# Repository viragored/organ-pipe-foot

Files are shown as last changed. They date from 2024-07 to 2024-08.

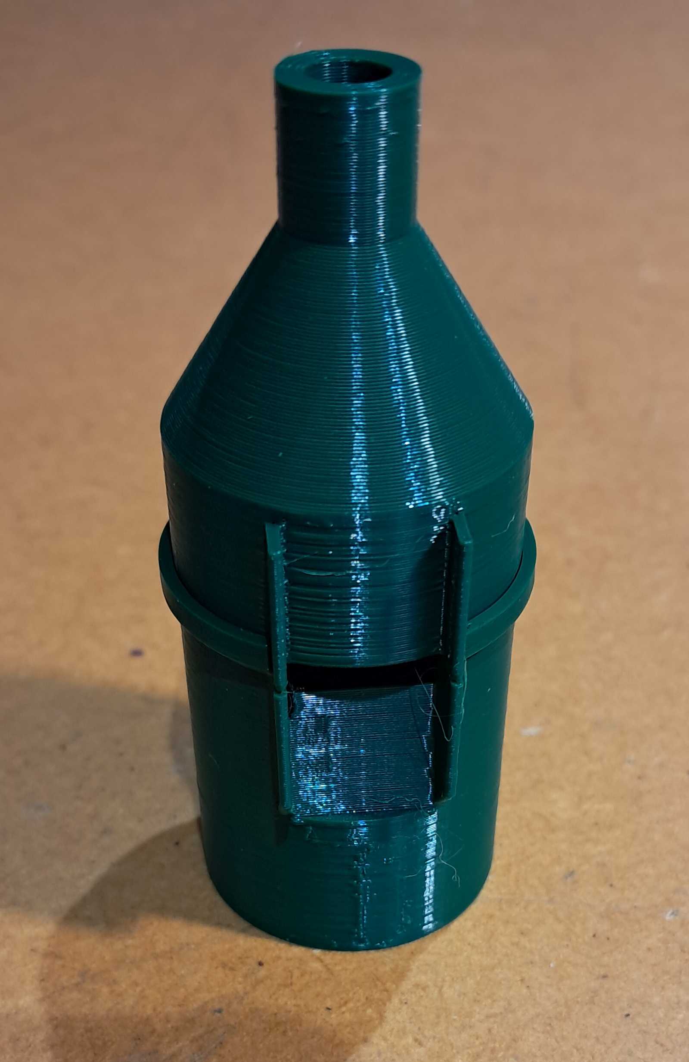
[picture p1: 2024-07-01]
foot 3.jpg

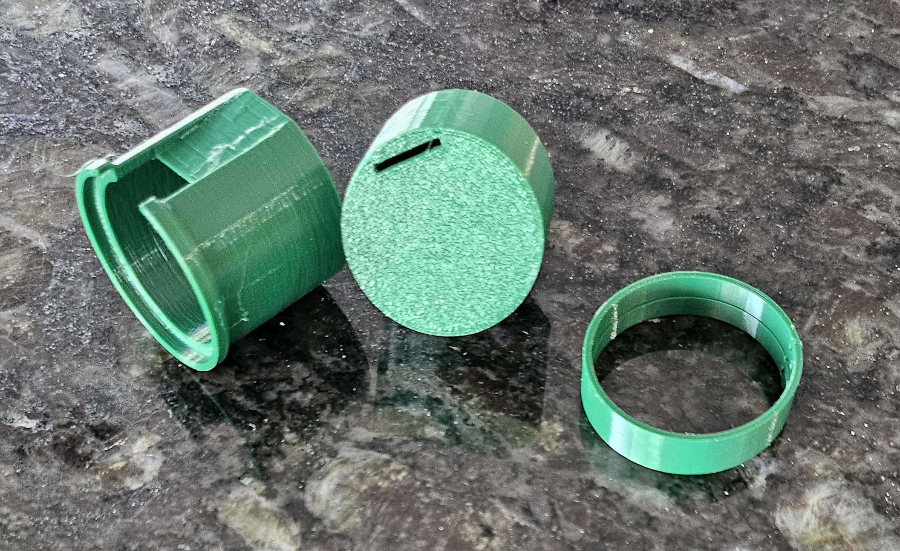
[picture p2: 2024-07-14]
V2 pic 1.jpg

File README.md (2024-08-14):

# organ-pipe-foot
OpenSCAD code to create organ pipe feet, customisable for size and shape

Aim: Produce a foot that must print without supports, based on these premises:
*  Walls will be thick enough to support PVC pipe while organ being moved, eg on a cart over rough ground
*  PVC pipe will be used for the resonating pipe
*  The pipe will be stopped, not open
*  Frequency will be given
*  Mouth height calculated using frequency in this formula (stopped pipe)
        MH = [3.018 - 0.233 ln f]^5 (MH = Mouth Height; f = Frequency; ln = natural log)
*  Flue (the slot in the languid through which air is blown) needs printing at high resolution for accuracy
*  flue_width is calculated from the Ising formula (link below)
*  Stem diameter, inside diameter of the stem connecting to the windchest
*  Foot length - from windchest to mouth to resonator = user's choice
*  Upper lip offset - achieved by aligning flue on languid
        [(https://www.colinpykett.org.uk/physics-of-voicing-organ-flue-pipes.htm#Offset)]

References:
*  [Formula using windsheet width (the thickness of the air stream coming from the flue) to get Ising's number at https://www.mmdigest.com/Tech/isingform.html
    and https://www.rwgiangiulio.com/math/wst.htm [Beware, Imperial units]
    windsheet_thickness =	(I^2 * f^2 * ρ * H^3) / 2P
        I = Ising's number; p = air density; P = air pressure; H = mouth height ]
*  Mouth height: a = 440Hz, stopped MH = 8.1 (https://www.rwgiangiulio.com/math/mouthheight.htm)
*  [Pipe length is: flue to stopper base - the pipe width + stopper 
        pipe_length = 3386 / f - pipe_internal_diameter (plus a bit of headroom?)
        (https://www.rwgiangiulio.com/math/pipelength.htm)
        (https://www.ccoors.de/webpipecalc/)]
*  Upper lip offset: (https://www.colinpykett.org.uk/physics-of-voicing-organ-flue-pipes.htm#Offset)

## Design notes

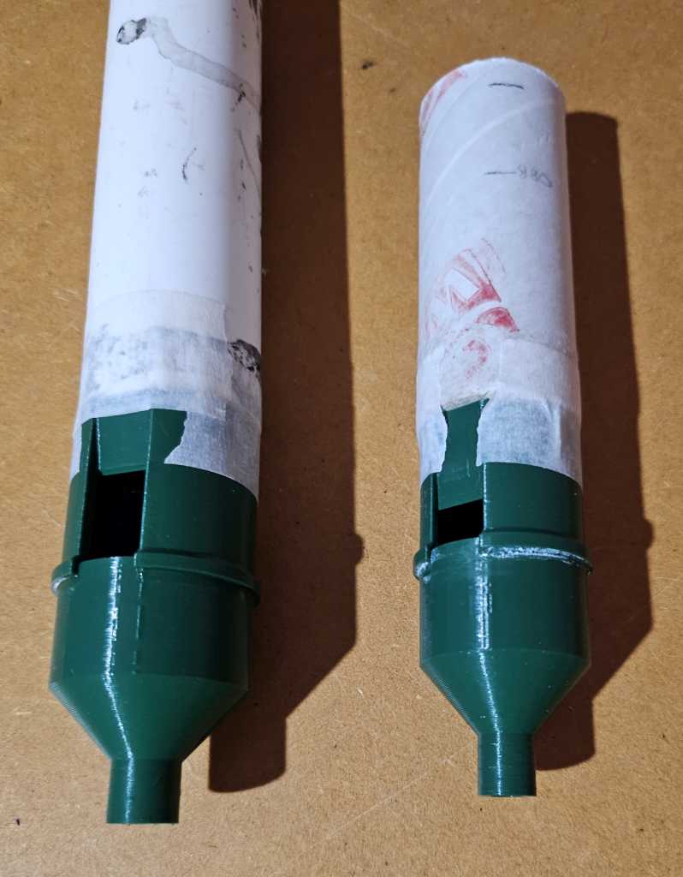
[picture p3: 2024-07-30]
V3 2.jpg

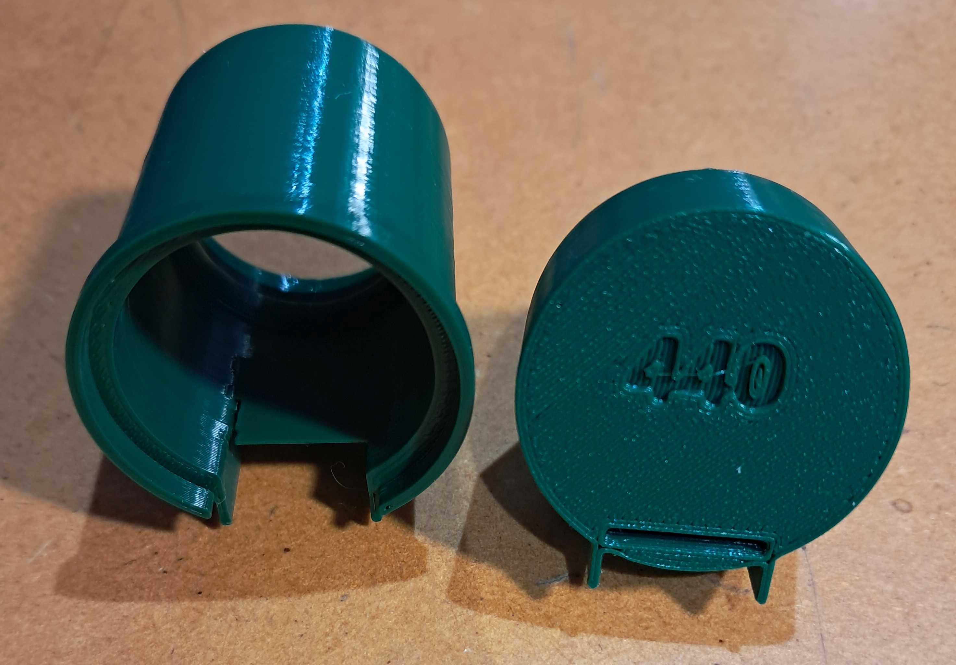
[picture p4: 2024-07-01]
foot 2.jpg

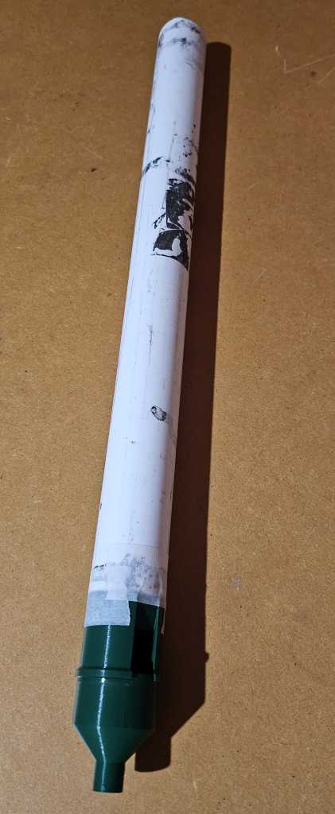
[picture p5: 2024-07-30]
V3 1.jpg

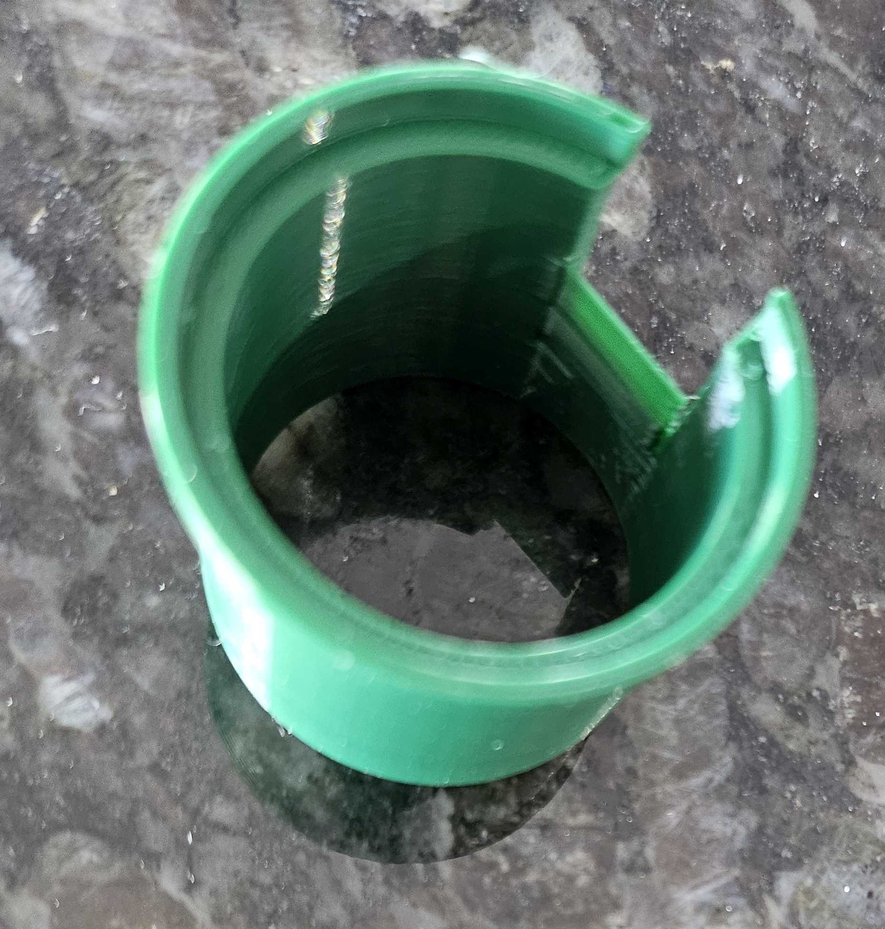
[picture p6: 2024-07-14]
V2 pic 2.jpg

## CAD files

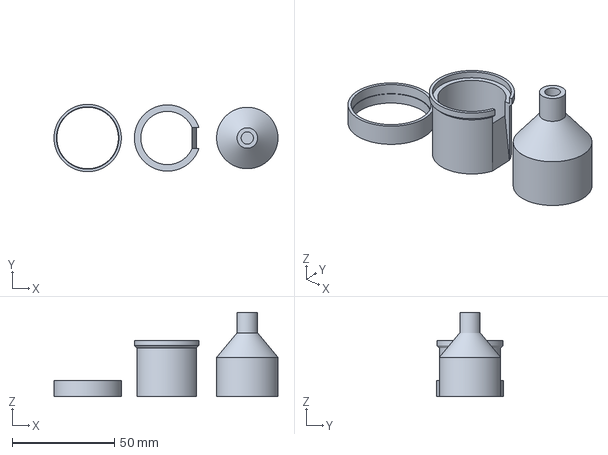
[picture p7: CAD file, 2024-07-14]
2nd prototype 880.3mf
109.4 x 32.9 x 41.3 mm

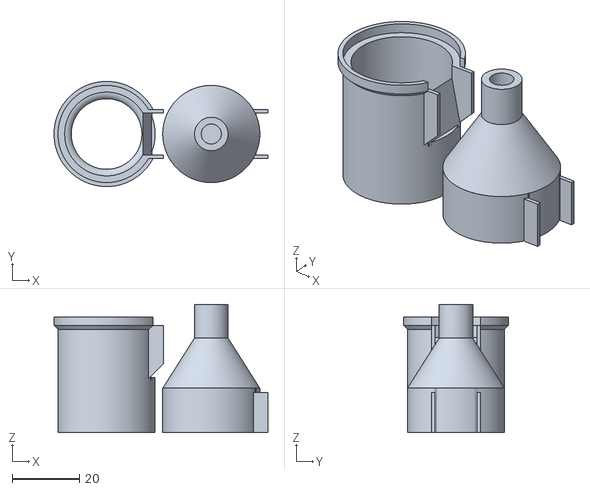
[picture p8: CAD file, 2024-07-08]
1st prototype.stl
63.9 x 31.4 x 38.3

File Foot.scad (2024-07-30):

/*                             Version 3: 23 July 2024
Notes:
Inspiration: 3D model "smaller pipe for 25 mm tube" (https://www.thingiverse.com/thing:6534684/files)
Aim: Produce a foot that must print without supports, based on these premises:
*  Walls will be thick enough to support PVC pipe while organ being moved, eg on a cart over rough ground
*  PVC pipe will be used for the resonating pipe
*  The pipe will be stopped, not open
*  Frequency will be given
*  Ising's number will be given (affects sound character of pipe, used in flue calculation)
*  Pressure of air at the pipe will be given
*  Mouth height calculated using frequency in this formula (stopped pipe)
        MH = [3.018 - 0.233 ln f]^5 (MH = Mouth Height; f = Frequency; ln = natural log)
*  Flue (the slot in the languid through which air is blown) needs printing at high resolution for accuracy
*  Stem diameter, inside diameter of the stem connecting to the windchest
*  Foot length - from windchest to mouth to resonator = user's choice
*  Upper lip offset - achieved by aligning flue on languid
        [(https://www.colinpykett.org.uk/physics-of-voicing-organ-flue-pipes.htm#Offset)]
References:
* Formula using windsheet width (the thickness of the air stream coming from the flue) to get Ising's number at https://www.mmdigest.com/Tech/isingform.html
    and https://www.rwgiangiulio.com/math/wst.htm [Beware, Imperial units : inch_mm = 25.39]
    windsheet_thickness D =	(I^2 * f^2 * )ρ * H^3)) / 2P
        I = Ising's number; p = air density; P = air pressure; H = mouth height 
        Solution from OpenAI: https://chatgpt.com/share/9501fe4e-4f52-485f-864d-c0a950776f9c
*  Pipe length is: flue to stopper base - the pipe width + stopper 
        pipe_length = 3386 / f - pipe_internal_diameter (plus a bit of headroom?) : INCHES !!
        (https://www.rwgiangiulio.com/math/pipelength.htm)  (https://www.ccoors.de/webpipecalc/)
*  Upper lip offset: (https://www.colinpykett.org.uk/physics-of-voicing-organ-flue-pipes.htm#Offset)
TO BE DONE - 
Make top of lip circular up to height of coupler
Harmonic Bridge aka Frein aka Beard? On or Off 
        (https://www.youtube.com/watch?v=bHBOwiEf6FM and Colin Pykett, below)
*/
// Definitions
// Design parameters

// CHOOSE these:
make = "f"; // f makes a foot, s makes a stopper, else makes nothing
ears_on = 1; // 1 = make ears, 0 = no ears
coupler_on = 1; // 1 = make coupler, 0 = no coupler

// SET these:
PVC_outside = 34; // outside diameter of PVC pipe resonator
PVC_inside = 28; // inside diameter of PVC pipe resonator
frequency = 233.08; // A#3 // Hz of target pipe, used to calculate mouth height
//frequency = 174.61; // F3 bass // Hz of target pipe, used to calculate mouth height
pipe_diameter = PVC_inside; // inside diameter of foot - same as PVC inside
stem_diameter = 6; // inside diameter of tube to couple with windchest
stem_length = 10; // length of pipe to couple with windchest
lower_body_length = 12; // length of lower pipe between stem and languid section
lower_top_length = 18; // length of lower section with languid that mates with upper
upper_length = 30; // user choice: length of upper part
// for stopper
disc_thick = 6; // thickness of stopper
knob_height = 25;
knob_diameter = 15;
knob_stand = 8; // height of knob base
knob_stretch = 2; // factor to multiply knob_height
screw_thread = 4; // diameter of fastening screw
screw_head = 8; // diameter of screw head
screw_free = 5; // length of thread to keep unused within knob (remember to add in disc, used to save cutting screws)
nut_diameter = 7.8; // diameter of hex nut across points
nut_thick = 3.2; // thickness of nut
o_ring_thick = 2.2; // thickness of o_ring

// REVIEW these
Ising = 2.5; // Ising's number for type of pipe sound, set mid-range
Pressure = 988; // air pressure reaching pipe, in Pascals : 988 = ~ 4 ins/ 10 cms H2O
rho = 1.2; // standard air density in Kg/M^3
inch_mm = 25.39; // conversion factor
wall_thick = 3; // thickness of walls in this foot
languid_thick = 1.25; // thickness of the languid (flat plate with air hole)
flue_offset_factor = 0.5; // adjust this amount of flue depth relative to lip (negative moves towards centre)
wind_factor = 0.4; // max proportion of pipe diameter that flue can be
ear_thick = 1; // thickness of the ears
ear_height = 5; // ear protrusion
upper_ear_length = 0.75; // proportion of upper body the ears will cover - too long can clash with coupler
collar_thick = 1.2; // thickness of the joining collar
collar_height = 2.5; // height of joining collar
coupler_height = 15; // height of PVC coupler
coupler_thick = 2.5; // thickness of PVC coupler
printer_fit = 0.2; // amount to allow for printer fitting curved parts
// internal parameters quick for preview, smooth curves for render
$fs = $preview ? 1 : 0.15;
$fa = $preview ? 3 : 2;
epsilon = 0.01; // tiny offset to ensure cuts go through
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

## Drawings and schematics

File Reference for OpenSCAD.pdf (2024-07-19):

0

1

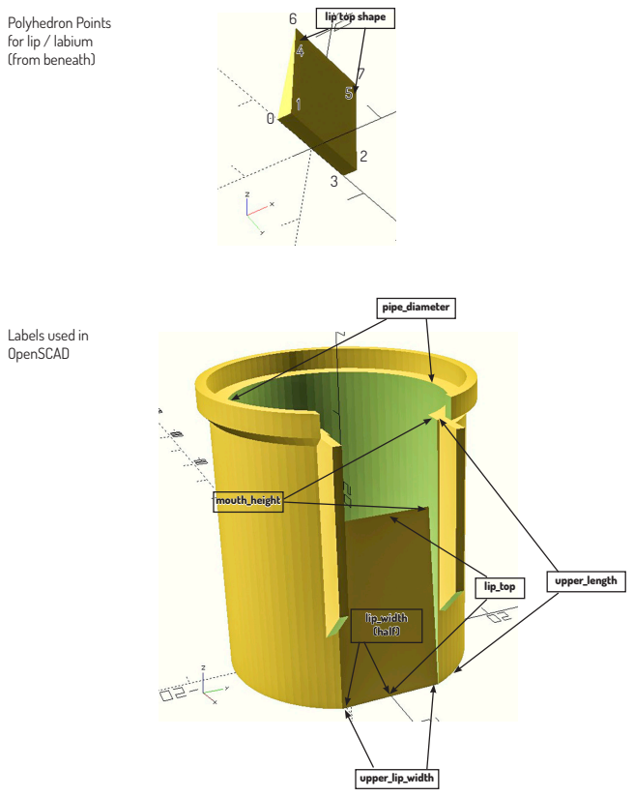
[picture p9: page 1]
lip top shape; upper_lip_width; lip_top; upper_length; mouth_height; lip_width (half); pipe_diameter

Polyhedron Points
for lip / labium
(from beneath)

Labels used in
OpenSCAD

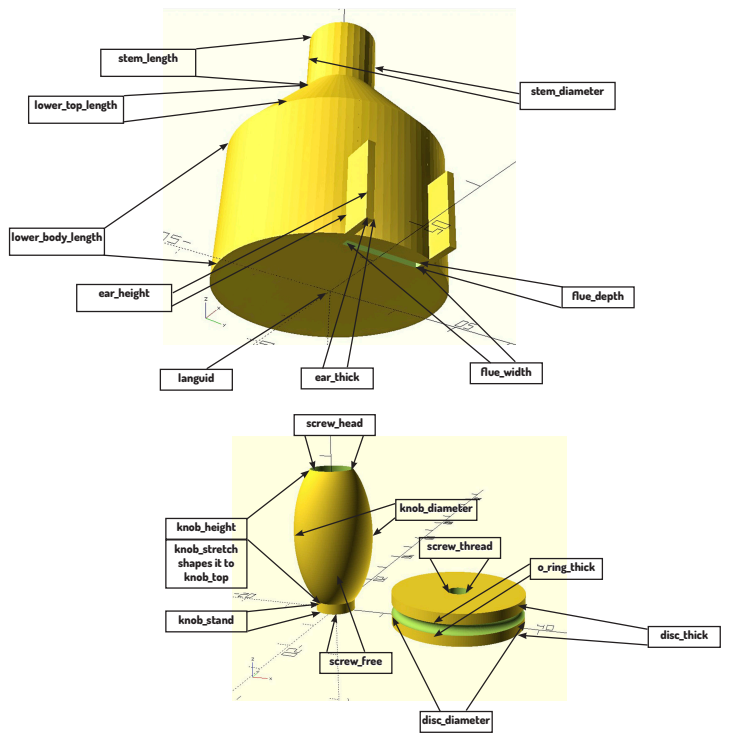
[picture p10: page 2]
flue_depth; flue_width languid; ear_thick; stem_diameter; stem_length; lower_body_length; lower_top_length; ear_height; disc_thick; disc_diameter; knob_diameter; knob_stand; knob_height knob_stretch shapes it to knob_top; screw_free; o_ring_thick; screw_thread; screw_head

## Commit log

2024-07-08 Add files via upload
    First prototype from the OpenSCAD file
    [1st prototype.stl]
2024-07-16 Add files via upload
    Added option to print a pipe stopper, also parametric
    [Foot.scad]
